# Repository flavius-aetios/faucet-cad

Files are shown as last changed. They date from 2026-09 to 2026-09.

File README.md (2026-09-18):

# Проставка для кухонного смесителя

Параметрическая модель CadQuery, которая меняет наклон выдвижной лейки,
чтобы направить струю вертикально. Текущий вариант рассчитан на коррекцию **13°**
по фотографии и посадочную часть лейки **Ø22 × 23 мм**.

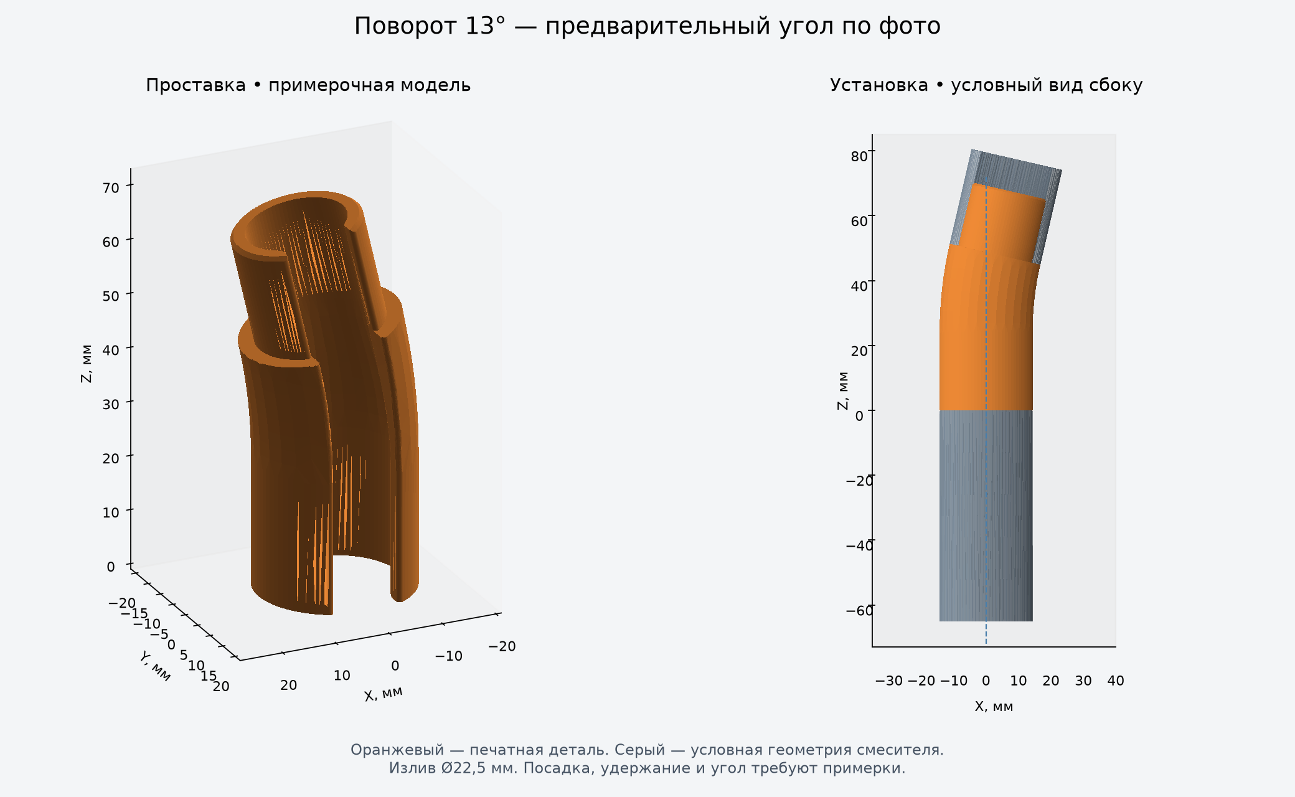
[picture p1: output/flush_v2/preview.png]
Вариант v2 и условная схема установки


**Состояние на 18.09.2026:** выбраны нижний **IN 22.6** и верхний **OUT 23.0**.
Подготовлен [вариант v2 для согласования и анализ печати](PROPOSAL_V2.md):
корпус Ø28,5 мм заподлицо на стыках, паз 12 мм, скругления R0,6 мм.
Новые STL/STEP находятся в **[output/flush_v2](output/flush_v2/)**;
старые файлы в корне `output/` сохранены для сравнения.
Результаты примерок записаны в [FIT_LOG.md](FIT_LOG.md).
Внутренний диаметр излива измерен: **22,5 мм**. Цель — плотная верхняя посадка
адаптера и свободное скольжение лейки в нижней. Надёжность удержания и фактическое
направление струи предстоит проверить. STL уточнён после замечания о видимых гранях.

## Что сохранено

- [model.py](model.py) — исходник модели; [parameters_flush_v2.json](parameters_flush_v2.json) —
  предлагаемые размеры; [parameters.json](parameters.json) — предыдущий вариант.
- [Фото референсы](<Фото референсы/>) — все четыре исходные фотографии с замерами.
- [output/flush_v2](output/flush_v2/) — новая полная проставка и два контрольных образца,
  условная сборка, изображения и отчёты; [output](output/) — также предыдущая серия.
- [PROPOSAL_V2.md](PROPOSAL_V2.md) — изменения, анализ сопла 0,4 мм и выбор PLA/PETG;
  [DESIGN.md](DESIGN.md) — исходная конструкция и история настройки окружения.
- `.vscode/` — настройки Python/OCP CAD Viewer и запуск через Ctrl+Shift+B.
- `pyproject.toml`, `uv.lock`, `.python-version` — воспроизводимое Python-окружение.

Папки `.venv`, кэши и временные диагностические установки в Git не включены:
окружение создаётся заново на другом компьютере из `uv.lock`.
STL уже можно открыть в Bambu Studio без установки CadQuery.

## Открыть на другом компьютере: Windows / PowerShell

Нужны Git, [uv](https://docs.astral.sh/uv/getting-started/installation/) и VS Code.
Для доступа к приватному репозиторию войти в свой аккаунт GitHub.

```powershell
git clone https://github.com/flavius-aetios/faucet-cad.git
Set-Location faucet-cad
uv sync --locked --cache-dir .uv-cache
code --install-extension ms-python.python
code --install-extension ms-toolsai.jupyter
code --install-extension bernhard-42.ocp-cad-viewer
code .
```

`uv` создаёт `.venv` с Python 3.11 и версиями библиотек из lock-файла.
Путь клонирования может быть любым: настройки проекта используют `${workspaceFolder}`.
Открывать в VS Code нужно **папку проекта**, чтобы её настройки применились.

1. Если VS Code не выбрал Python автоматически, выполнить `Python: Select Interpreter`
   и выбрать `.venv\Scripts\python.exe` внутри клонированной папки.
2. Открыть `model.py`: справа должен открыться OCP CAD Viewer.
3. Для нового варианта: **Terminal → Run Task → OCP: Show flush rounded v2 proposal**.
   **Ctrl+Shift+B** показывает прежнюю модель для сравнения. Открытие исходника само
   по себе не отправляет модель; задача выполняет программу с `--view`.

Альтернатива из терминала в папке проекта:

```powershell
& '.\.venv\Scripts\python.exe' '.\model.py' --parameters parameters_flush_v2.json --output-dir output/flush_v2 --view
```

Для генерации файлов без Viewer и проверки результата:

```powershell
& '.\.venv\Scripts\python.exe' '.\check_environment.py'
& '.\.venv\Scripts\python.exe' '.\model.py' --parameters parameters_flush_v2.json --output-dir output/flush_v2
& '.\.venv\Scripts\python.exe' '.\verify_exports.py' --output-dir output/flush_v2
& '.\.venv\Scripts\python.exe' '.\analyze_print.py' --output-dir output/flush_v2
```

Сохранённые отчёты относятся к исходному компьютеру; эти команды обновляют их
по результатам проверок на новом компьютере.

## Уже исправленные проблемы окружения

- **Python падает при завершении:** на Windows совместная загрузка CasADi 3.8.0
  и NLopt 2.11.0 приводила к `0xC0000005`. Зафиксирована проверенная пара
  **CasADi 3.8.0 / NLopt 2.9.1**. Использовать `uv sync --locked`, чтобы сохранить её.
- **PowerShell: неожиданный токен `-m`:** расширению задан префикс `& ` через
  `OcpCadViewer.advanced.shellCommandPrefix`. После изменения настроек выполнить
  `Developer: Reload Window`. В ручных командах перед путём к Python в кавычках
  также нужен `&`.
- **В Viewer логотип OCP:** выполнить `model.py --view` или Ctrl+Shift+B.

Инструкции и настройки VS Code проверены на Windows с PowerShell. При переносе
на Linux/macOS путь к Python — `.venv/bin/python`; нужно также изменить Windows-путь
в `.vscode/tasks.json`/`settings.json` и убрать PowerShell-префикс `& `.

## Следующий шаг: контрольные образцы v2

Для рабочей детали предлагается PETG, PLA подходит для примерок. Изменение
материала, паза и толщины стенок требует проверки посадок на новой геометрии.
Сначала напечатать в выбранном материале:

- [OUT 23.0 v2](output/flush_v2/pin_gauge_OD_23.0.stl) — верхняя посадка длиной 20 мм.
- [IN 22.6 v2](output/flush_v2/socket_gauge_ID_22.6.stl) — короткий нижний образец.

На всех образцах есть выпуклые подписи: **IN** — внутренний диаметр,
**OUT** — наружный, затем размер в миллиметрах. Образцы можно печатать вместе
на одной пластине и различать по надписям. [Пример маркировки](output/flush_v2/labeled_samples.png).
Штрихи утолщены до **1 мм**, точка увеличена до **1,2 мм**, рельеф — **0,8 мм**.
Новая серия лежит отдельно от старой; надписи обозначают размер, а не ревизию.

Для сопла 0,4 мм: слой 0,2 мм, 4 стенки, масштаб 100%. Проверить каждый образец
рукой без запрессовки: не входит / входит плотно / есть люфт. По результату изменить
зазоры в `parameters_flush_v2.json`, затем пересоздать вариант v2.

Адаптер должен оставаться в изливе при извлечении лейки. Отдельной защёлки пока нет:
верхняя посадка удерживается трением, возвратный шланг возвращает лейку в адаптер.
Анализ стенок и нависаний, настройки и порядок установки описаны
в [PROPOSAL_V2.md](PROPOSAL_V2.md).

## Сохранить дальнейшие изменения

После изменения размеров и повторной генерации:

```powershell
git add .
git commit -m "Update adapter dimensions and printable models"
git push
```

На другом компьютере перед началом работы: `git pull`, затем
`uv sync --locked --cache-dir .uv-cache`.

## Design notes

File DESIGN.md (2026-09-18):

# Угловая проставка для выдвижной лейки

**Обновление 18.09.2026:** пользователь выбрал верхний образец **OUT 23.0**.
Подготовлен [вариант v2 для согласования](PROPOSAL_V2.md): корпус Ø28,5 мм,
паз 12 мм, скругления R0,6 мм; файлы в `output/flush_v2/`.
Параметры и инструкции ниже описывают **предыдущую версию**, сохранённую для сравнения.

Текущая версия — модель для проверки посадки. Проставка меняет положение всей
лейки и устанавливается между лейкой и изливом. Вода остаётся в штатном шланге.
Паз сбоку позволяет надеть проставку на шланг, не разбирая соединение.

**Примерка 17.09.2026:** нижний образец IN 22.6 подошёл. Верхние образцы до
OUT 22.6 включительно не обеспечили нужного удержания. Подготовлена следующая
серия OUT 22.7 / 22.8 / 22.9 / 23.0. Подробности: [FIT_LOG.md](FIT_LOG.md).
Полную проставку пока не печатать: её верхний хвостовик ещё не подобран.

## Исходные размеры

| Параметр | Значение | Основание |
|---|---:|---|
| Посадочная часть лейки | Ø22 × **23 мм** | Фото и поправка пользователя; оранжевые 12 мм ошибочны |
| Корпус лейки | Ø28,5 мм | Фото с размерами |
| Жёсткий буртик соединителя | Ø12 мм | Уточнение пользователя |
| Шланг | Ø11 мм | Уточнение пользователя |
| Глубина отверстия излива | Немного больше 23 мм | Уточнение пользователя; дальше изгиб |
| Внутренний диаметр излива | **22,5 мм** | Измерен пользователем 10.09.2026 |
| Коррекция угла | **13°** | Оценка по общему фото; пользователь поручил оценить по фото |

На общем фото направление корпуса лейки отличается от вертикальной стойки
примерно на 12–15°. Камера даёт перспективное искажение; точность 13° не является
результатом измерения. При примерке нужно проверить фактическое направление струи.

## Геометрия текущей версии

- Нижняя посадка Ø22,6 мм, глубина прямого участка 24 мм: диаметральный зазор
  0,6 мм и запас по высоте 1 мм. Диаметр выбран по успешной примерке короткого образца;
  скольжение по всей длине 23 мм ещё предстоит проверить на полной детали.
- Верхний хвостовик Ø22,5 мм, длина 20 мм, фаска на входе 0,6 мм.
  Это оставленный в полной модели прежний размер, который НЕ обеспечивает
  нужное удержание. Заменить его после выбора нового образца; это не размер к печати.
- Внутренний проход в хвостовике Ø18 мм; боковой паз 13 мм.
- Корпус Ø30,5 мм; поворот между нижней и верхней осями 13°.
- Высота между опорной плоскостью корпуса лейки и торцом излива 48 мм.
  В первой версии этот запас оставлен для соединителя и изгиба шланга.
  Лейка окажется ниже штатного положения; после примерки длину можно уменьшить.
- Общий габарит детали приблизительно 33,3 × 29,1 × 69,9 мм.

Целевая посадка: **адаптер плотно удерживается в изливе, лейка скользит в адаптере**.
Лейка должна выниматься без вытягивания адаптера, но не иметь заметного бокового
люфта. Для верхней посадки подбирается фактический натяг по печатным образцам;
совпадение чисел Ø22,5 в CAD само по себе удержание не гарантирует.
В модели **нет отдельной защёлки, магнита или механического стопора от проворота**.
Натяжение штатного шланга возвращает лейку в нижнее гнездо. Если трения верхнего
хвостовика недостаточно и адаптер вращается или выходит вместе с лейкой,
потребуется доработка крепления. Образцы проверяют посадку, но не заменяют
проверку удержания всей конструкции при многократном извлечении лейки.

Длина жёсткого соединителя над посадочной частью не измерена. Поэтому отсутствие
его контакта со стенкой и свободный изгиб шланга проверяются при сборке.
Не вдавливать деталь, если шланг или соединитель упирается.

## Файлы

- `model.py` — параметрическая модель CadQuery.
- `parameters.json` — все изменяемые размеры в миллиметрах.
- `output/adapter_prototype.stl` — полная деталь для **примерочной** печати.
- `output/adapter_prototype.step` — точная CAD-геометрия.
- `output/socket_gauge_ID_22.6.stl` — проверенный нижний образец с новой маркировкой;
  повторная печать для подбора диаметра не нужна.
- `output/pin_gauge_OD_22.7.stl`, `22.8`, `22.9`, `23.0` — новые образцы верхнего хвостовика
  с полной длиной посадки 20 мм, пазом 13 мм, входной фаской 0,6 мм и основанием
  толщиной 2 мм, чтобы образец не ушёл внутрь излива. Общая высота образца 22 мм.
- `output/assembly_reference.step` — иллюстрация установки, **не для печати**.
  Длины серых моделей лейки и излива условные; шланг, кнопка и механизм фиксации
  не воспроизведены.
- `output/preview.png` — обзор детали и установки.
- `output/labeled_samples.png` — пример маркировки образцов.
- `output/geometry_report.json`, `export_validation.json` — проверки геометрии и экспорта.
- `check_surface.py`, `output/surface_quality.json` — измерение гладкости изгиба
  и отклонения треугольников STL от исходной поверхности.

## Грани, замеченные в STL

Исходная поверхность изгиба — гладкая B-spline. На 4141 проверенной точке
её отклонение от идеального кругового изгиба менее 0,00000003 мм. Выраженные
треугольные пятна в просмотрщике связаны с плоскими гранями STL и их освещением.
В STL эти грани действительно присутствуют; в исходном CAD таких заломов нет.

Экспорт уточнён: линейный допуск 0,005 мм вместо 0,03 мм, угловой 0,03 рад
вместо 0,08 рад. Перед экспортом удаляется ранее рассчитанная сетка отрисовки.
В версии от 10.09 число треугольников полной детали выросло с 18 636 до 119 100. В выборочной
проверке середины рёбер и центров треугольников внешнего изгиба наибольшее
измеренное отклонение снизилось с 0,1055 до 0,0094 мм. Это выборочное измерение,
а не доказанная граница ошибки в каждой точке всей модели. STL остаётся
треугольной сеткой; освещение без сглаживания может показывать грани и после уточнения.
Параметры экспорта описаны в [документации CadQuery](https://cadquery.readthedocs.io/en/stable/importexport.html).

## Первая печать на Bambu Lab, PLA

На каждом образце есть единая с ним площадка 16 × 14 × 2 мм с выпуклой надписью
высотой **0,8 мм**. **IN 22.6** означает внутренний диаметр 22,6 мм (образец на лейку),
**OUT 22.7** — наружный диаметр 22,7 мм (образец в излив). Все пять образцов
подписаны своим фактическим размером из параметров модели. Площадка находится
снаружи кольца, напротив бокового паза, и не меняет посадочные поверхности.
Это дополнительно проверяется в генераторе сравнением геометрии до/после маркировки.

Можно загрузить нужные STL одновременно в Bambu Studio и разложить их на одной
пластине. Каждый STL — одно связное тело с собственной надписью; печатать
площадкой на столе, надписью вверх. При слое 0,2 мм надпись занимает четыре слоя
над площадкой. Смена цвета не обязательна. Старый шрифт заменён геометрическими
буквами и цифрами с постоянной шириной штриха **1,0 мм**; десятичная точка —
квадрат **1,2 × 1,2 мм**. У штрихов нет сужающихся тонких концов. Шрифт из системы
больше не используется. В предпросмотре слайсера проверить слои надписей:
геометрия и связность проверены, но нарезка конкретным профилем принтера здесь не выполнялась.

Нижний диаметр Ø22,6 уже выбран пользователем по примерке.
Для верхней посадки напечатать `pin_gauge_OD_22.7.stl`, `22.8`, `22.9`, `23.0`
и примерять от меньшего диаметра к большему. Выбрать образец, который входит
на всю длину рукой и устойчиво держится; не забивать и не вдавливать силой.
Относительно измеренных Ø22,5 новые образцы дают номинальный натяг по диаметру
0,2 / 0,3 / 0,4 / 0,5 мм. Это размеры CAD, фактические размеры печати могут отличаться.
После выбора подставить результат в параметры: например, Ø22,8 означает
`outlet_diametral_clearance = -0.3`. Список новой серии задан в `pin_test_diameters`.
Сохранять прежние настройки материала и печати, чтобы сравнение было осмысленным.
STL импортировать в миллиметрах, масштаб 100%; не масштабировать модель для подбора посадки.

Для предполагаемого сопла 0,4 мм стартовые настройки: штатный профиль вашего PLA,
слой 0,2 мм, 4 периметра, 5 верхних/нижних слоёв, заполнение 25–30%.
Образцы стоят плоским основанием на столе. Полная деталь экспортирована нижним
торцом на Z=0, хвостовиком вверх. В предпросмотре слайсера проверить нависания;
внутренний переход пологий, отдельные поддержки конструкцией не предусмотрены.
При недостаточной адгезии добавить кайму 4–5 мм. Профиль температуры выбирать
по конкретному PLA и пластине, модель принтера пока не уточнена.

PLA здесь используется для примерки. Для постоянной эксплуатации у горячего
крана материал стоит выбирать с учётом нагрева и нагрузки; PETG обычно применяют
для держателей и зажимов благодаря вязкости и температурной стойкости
([руководство Prusa](https://help.prusa3d.com/article/petg_2059)).

После примерки надеть проставку боком на шланг, вставить лейку в нижнюю часть,
а хвостовик — в излив. Повернуть проставку так, чтобы она компенсировала наклон
в плоскости изгиба крана. Поддерживая сборку рукой, проверить посадку, возврат
шланга и вертикальность небольшой струи. Пока удержание не проверено,
не считать конструкцию законченной.

## Запуск

```powershell
.\.venv\Scripts\python.exe model.py
.\.venv\Scripts\python.exe verify_exports.py
```

Для показа в уже открытом OCP CAD Viewer:

```powershell
.\.venv\Scripts\python.exe model.py --view
```

Открытие `model.py` показывает исходный код, а модель отправляется только при
выполнении программы с `--view`. В VS Code открыть именно папку `Смеситель`
(File → Open Folder), открыть Viewer и нажать **Ctrl+Shift+B**: задача
`OCP: Show faucet adapter` запускает нужный Python с нужными аргументами.

При запуске из любой папки PowerShell можно выполнить:

```powershell
Set-Location -LiteralPath 'C:\Users\mihai\Desktop\DIY\Смеситель'
& '.\.venv\Scripts\python.exe' '.\model.py' --view
```

Для автоматических команд расширения в `.vscode/settings.json` задан
`OcpCadViewer.advanced.shellCommandPrefix: "& "`. Это настройка для PowerShell:
путь к программе в кавычках требует оператора вызова `&`. Если открытый терминал
backend уже показал ошибку `Непредвиденный токен "-m"`, в нём можно повторить:

```powershell
& 'C:\Users\mihai\Desktop\DIY\Смеситель\.venv\Scripts\python.exe' -m ocp_vscode --backend --port 3939
```

Backend обслуживает измерения в Viewer; загрузку нашей геометрии выполняет
именно `model.py --view`. Для ручного запуска модели использовать другой терминал,
пока backend работает. После изменения настроек можно выполнить команду VS Code
`Developer: Reload Window`, чтобы расширение перезапустилось с новым префиксом.

Угол меняется в `correction_angle_deg`; посадки — в `socket_diametral_clearance`
и `outlet_diametral_clearance`. Измеренный диаметр излива задаётся параметром
`outlet_bore_diameter` (22,5 мм). Положительный зазор уменьшает хвостовик,
отрицательный задаёт номинальный натяг. Повторный запуск перезаписывает экспорт.

## Исправление ошибки Python при завершении

В исходном окружении CadQuery 2.8.0 / CasADi 3.8.0 / NLopt 2.11.0 импорт
проходил успешно, но процесс завершался с `0xC0000005` (access violation).
Минимальное воспроизведение: `import casadi; import nlopt`. По отдельности
CasADi, NLopt, OCP и VTK завершались с кодом 0.

Для Windows зафиксирована проверенная пара **CasADi 3.8.0 / NLopt 2.9.1**
в `pyproject.toml` и `uv.lock`. CadQuery и OCP не заменялись.
Обычный запуск модели не подавляет ошибки Windows и не использует принудительный
выход для обхода очистки памяти. `check_environment.py` запускает отдельные
проверки решателей и CadQuery, проверяет реальный код завершения и сохраняет отчёт.
Подобная проблема описана [в CadQuery #1911](https://github.com/CadQuery/cadquery/issues/1911)
и [в repackage-ocp](https://github.com/bernhard-42/repackage-ocp).

```powershell
uv sync --cache-dir .uv-cache
.\.venv\Scripts\python.exe check_environment.py
```

Если VS Code или Jupyter уже загрузил прежний NLopt, перезапустить его Python-ядро,
чтобы оно использовало обновлённую библиотеку.

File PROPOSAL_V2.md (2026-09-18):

# Вариант v2 для согласования — 18.09.2026

Пользователь выбрал верхний образец **OUT 23.0**. Нижняя посадка **IN 22.6**
подтверждена ранее. Подготовлен отдельный вариант с уменьшенным корпусом и
скруглённым пазом: [STL](output/flush_v2/adapter_prototype.stl),
[STEP](output/flush_v2/adapter_prototype.step),
[параметры](parameters_flush_v2.json).
Прежние файлы в корне `output/` сохранены для сравнения и относятся к прошлой серии.

Вариант v2 и условная установка

## Предлагаемые изменения

| Параметр | Предыдущая версия | Вариант v2 |
|---|---:|---:|
| Наружный диаметр корпуса | 30,5 мм | **28,5 мм** |
| Верхняя посадка полной детали | 22,5 мм, устаревший размер | **23,0 мм**, выбран по образцу |
| Нижняя посадка | 22,6 мм | 22,6 мм |
| Ширина бокового паза | 13 мм | **12 мм** |
| Продольные углы паза | Острые | **R0,6 мм**, наружные и внутренние |
| Внутреннее сужение | Сосредоточено в конце изгиба | Плавно распределено по изгибу |

Корпус совпадает по номинальному диаметру с изливом и лейкой в местах стыков;
прежняя наружная ступенька 1 мм на сторону убрана. Это не герметичный стык:
реальная печать и подвижная лейка оставляют зазоры. Изгиб выступает в сторону
от нижней оси, поэтому общий габарит по X около 32,6 мм не означает диаметр 32,6 мм.
Поверхность в зоне изгиба аппроксимируется CAD-лофтом между круговыми сечениями.

Паз 12 мм оставляет номинально 1 мм относительно мягкого шланга Ø11 мм.
Скругления снимают углы, сохраняя ширину узкой части паза. Адаптер надевается
сбоку на мягкий участок шланга: жёсткий буртик Ø12 мм через паз с нулевым зазором
пропускать не предполагается. Торцы имеют прежние входные фаски 0,6 мм;
R0,6 относится именно к продольным краям паза, а не ко всем рёбрам детали.

Прямой участок нижнего гнезда по-прежнему 24 мм, хвостовик 20 мм,
расстояние между торцами лейки и излива 48 мм, угол 13° по фото.
Внутреннее сужение начинается выше прямого гнезда; его конечный проход Ø18 мм.
Длину жёсткого соединителя не измеряли, поэтому свободный изгиб шланга и отсутствие
упора соединителя проверяются на полной детали.

## Печать соплом 0,4 мм

Номинальная радиальная толщина вдали от скруглений паза:

| Участок | Толщина |
|---|---:|
| Нижнее гнездо | **2,95 мм** |
| Край нижней входной фаски | 2,35 мм |
| Верхний хвостовик | **2,50 мм** |
| Край верхней входной фаски | 1,90 мм |

Эти размеры допускают несколько линий экструзии соплом 0,4 мм. Они не являются
расчётом прочности или доказанной минимальной толщиной во всех точках скруглений.
Уменьшение корпуса ослабляет нижнее разрезное кольцо; более узкий паз и смена
материала тоже меняют его упругость. Старые результаты примерки не гарантируют
одинаковую силу удержания новой детали.

Ориентация: **широким нижним торцом на стол, хвостовиком вверх**, как экспортировано.
Так кольцо пружинит преимущественно в плоскости слоёв. Изгиб всей проставки
при рывке лейки всё равно нагружает связи между слоями.

Проверка нормалей STL после сглаживания внутреннего перехода дала максимум
**16,65° от вертикали** для нависающих поверхностей выше нижней фаски.
Площадь таких поверхностей круче 45° — **0 мм²**. Контакт со столом и зона
нижней входной фаски до Z=0,61 мм исключены из этой оценки. Нижняя фаска имеет
наклон 45°. По этой геометрии поддержки не требуются. Это анализ поверхности,
а не проверка траекторий, охлаждения и качества конкретного профиля слайсера.

Стартовые настройки для Bambu Studio:

- Сопло 0,4 мм, масштаб **100%**, слой **0,2 мм** для примерки или **0,16 мм**
  для более гладкой внешней поверхности.
- **4 периметра**, 5 верхних и нижних слоёв, заполнение 30%. В тонких стенках
  большую часть сечения займут периметры; заполнение 100% не обязательно.
- Поддержки выключены; перед печатью проверить послойный предпросмотр.
- При необходимости кайма 4–5 мм, особенно для высокой полной детали.
- Шов разместить со стороны паза, по возможности вне основных посадочных дуг.
  Сохранить проверенную компенсацию первого слоя и не масштабировать деталь
  для исправления посадки.
- Температуры, обдув и подготовка пластины — по профилю конкретного филамента
  и принтера. Модель Bambu Lab и марка филамента пока не указаны.

Маркировка образцов сохранена: штрих 1 мм, квадратная точка 1,2 мм,
выпуклый рельеф 0,8 мм. При слое 0,2 мм это четыре слоя над площадкой.

## PLA или PETG

**Предлагаю PETG для рабочей детали, PLA оставить для примерок.** Для разрезного
зажима полезны вязкость, хорошее сцепление слоёв и более высокая температурная
стойкость PETG. PLA проще печатать, но он более хрупкий и хуже переносит нагрев;
для постоянно нагруженной посадки рядом с горячим краном это нежелательно.
Свойства описаны в руководствах производителя:
[PETG](https://help.prusa3d.com/article/petg_2059),
[PLA](https://help.prusa3d.com/article/pla_2062).

Это выбор материала для следующего прототипа, а не гарантия долговременного
удержания. При нагреве и длительной нагрузке посадка может ослабевать.
PETG обычно хуже переносит нависания и чаще даёт нити, поэтому здесь полезны
пологий внутренний переход и сухой филамент по инструкции его производителя.
После смены PLA на PETG посадку нужно проверить заново.

## Что напечатать следующим

Перед полной деталью напечатать в выбранном материале два компактных образца:

- [OUT 23.0 v2](output/flush_v2/pin_gauge_OD_23.0.stl) — паз 12 мм, R0,6,
  полная длина посадки 20 мм и ограничительный фланец Ø28,5 мм.
- [IN 22.6 v2](output/flush_v2/socket_gauge_ID_22.6.stl) — новая толщина стенки,
  паз 12 мм и R0,6. Короткое кольцо экономит материал, но не проверяет скольжение
  лейки по всей глубине 24 мм.

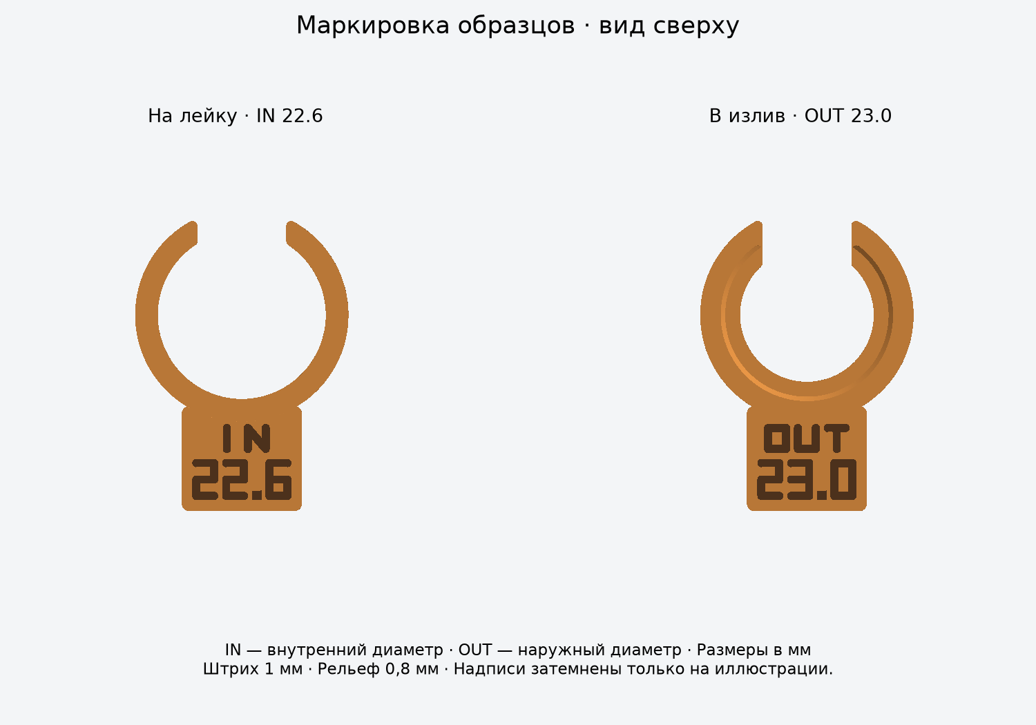
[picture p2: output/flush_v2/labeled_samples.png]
Образцы v2


Надписи обозначают размеры, а не ревизию. Не смешивать эти образцы со старыми:
у новых ширина паза 12 мм, видны скругления, наружный фланец 28,5 мм.
Выбранные Ø23,0 и Ø22,6 сохраняем до результатов проверки новой геометрии.
После печати полной детали проверить удержание при извлечении лейки,
отсутствие проворота, свободный шланг и направление струи.

## Воспроизведение и проверка

В VS Code: **Terminal → Run Task → OCP: Show flush rounded v2 proposal**.
Стандартная задача Ctrl+Shift+B пока показывает прежний вариант для сравнения.
Для новой версии из терминала в папке проекта:

```powershell
& .\.venv\Scripts\python.exe model.py --parameters parameters_flush_v2.json --output-dir output/flush_v2 --view
& .\.venv\Scripts\python.exe verify_exports.py --output-dir output/flush_v2
& .\.venv\Scripts\python.exe analyze_print.py --output-dir output/flush_v2
```

Все три STEP прошли проверку валидности единого тела; все три STL — проверку
замкнутости, связности, согласованности ориентации и объёма относительно STEP.
Отчёты: [геометрия](output/flush_v2/geometry_report.json),
[экспорт](output/flush_v2/export_validation.json),
[печать](output/flush_v2/print_analysis.json).
Пересечение хвостовика с условным изливом в отчёте ожидаемо: CAD Ø23,0 больше
измеренного отверстия Ø22,5. Это номинальный натяг; упругая деформация и реальные
печатные размеры в CAD-сборке не моделируются.

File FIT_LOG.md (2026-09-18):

# Результаты примерок

## 18.09.2026 — выбран OUT 23.0, предложена ревизия v2

Пользователь распечатал следующую серию: **23,0 мм подходит лучше всего**.
Нижняя посадка остаётся 22,6 мм. Эти номиналы перенесены в
`parameters_flush_v2.json`; прежний `parameters.json` сохранён для сравнения.

Пользователь измерил наружный диаметр тестового корпуса 30,5 мм и уточнил,
что наружные диаметры излива и лейки 28,5 мм. Предложен корпус 28,5 мм,
паз 12 мм для мягкого шланга 11 мм, скругления продольных углов R0,6 мм.
Подробности и анализ печати соплом 0,4 мм: [PROPOSAL_V2.md](PROPOSAL_V2.md).

Из-за изменения стенки, паза и возможного перехода на PETG подготовлены два
контрольных образца в `output/flush_v2/`. Сам вариант v2 ещё не примеряли.
Нижеследующие записи относятся к предыдущим этапам и не описывают статус v2.

## 17.09.2026 — первая печатная серия

Со слов пользователя, материал PLA, принтер Bambu Lab. Точные профиль и модель
принтера, измеренные размеры напечатанных деталей не сообщались.

| Образец | Результат | Решение |
|---|---|---|
| socket_gauge_ID_22.6 | Подошёл | Принять нижний диаметр 22,6 мм; на полной детали проверить всю длину посадки |
| pin_gauge_OD, вплоть до 22.6 | Держится слабо, выпадает от небольшого касания | Увеличить тестовые диаметры до 22,7 / 22,8 / 22,9 / 23,0 мм |
| Маркировка прежних образцов | Плохие надписи, пропуски и точки | Штрих 1,0 мм, квадратная точка 1,2 мм, рельеф 0,8 мм |

Размеры в названиях — номиналы CAD. Измеренный внутренний диаметр излива —
22,5 мм; его не меняем по косвенным результатам печати. Слабая посадка образца
22,6 мм сама по себе не доказывает ошибку этого измерения.

Новая серия сохраняет длину посадки 20 мм, проход Ø18 мм, паз 13 мм и фаску
0,6 мм. Изменён только наружный диаметр посадки и нерабочая маркировка.
Уже найденный нижний образец сохранён с новой надписью, остальные старые образцы
убраны из `output/`, чтобы не перепутать серии.

**Полная проставка ещё не готова к окончательной печати.** В ней нижний диаметр
изменён на 22,6 мм, верхний пока оставлен прежним (22,5 мм). После следующей
примерки заменить `outlet_diametral_clearance` на `22.5 - выбранный диаметр`.

Примерять новые образцы от меньшего к большему, не забивать. Нужен размер,
который входит на всю длину и не выпадает от касания. Затем на полной проставке
проверить, что извлечение лейки не вытягивает адаптер и не проворачивает его.

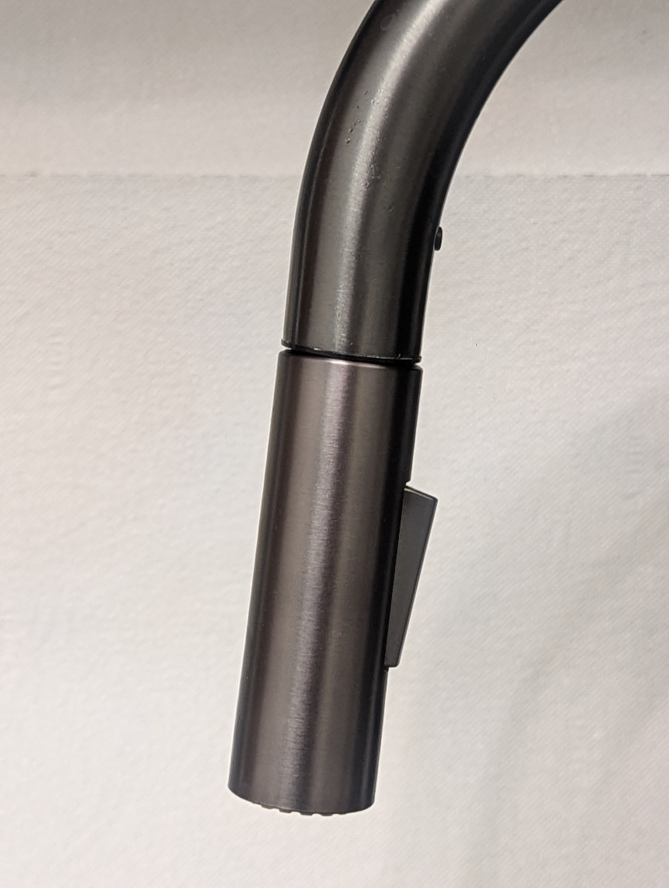
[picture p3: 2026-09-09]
Фото референсы/Крупный план форсунки.jpg

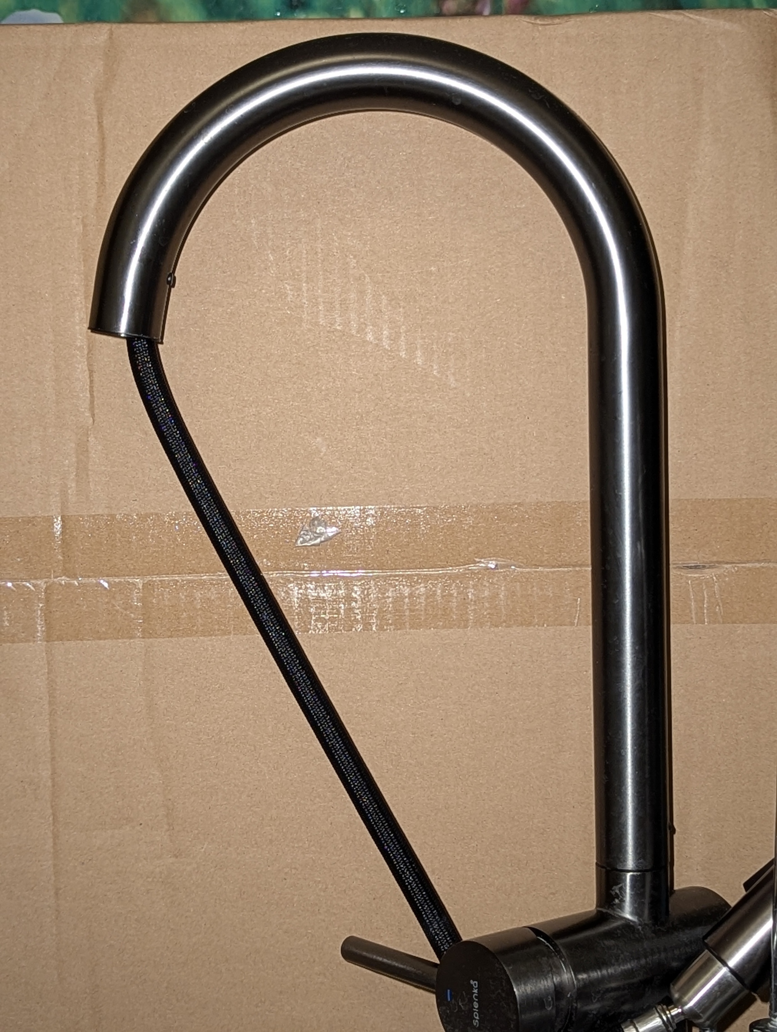
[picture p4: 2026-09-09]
Фото референсы/Общий вид с выдвинутой форсункой.jpg

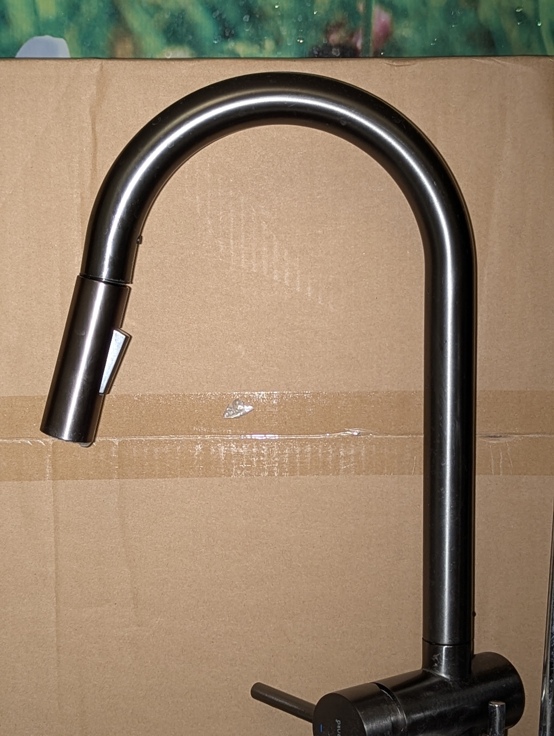
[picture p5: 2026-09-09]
Фото референсы/Общий вид на смеситель.jpg

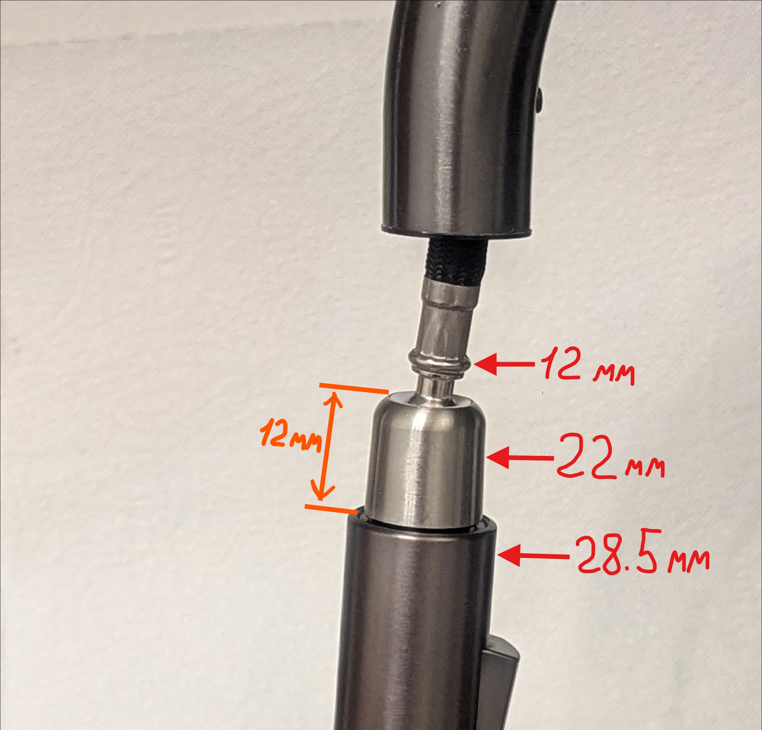
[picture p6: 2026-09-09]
Фото референсы/Размеры_.jpg

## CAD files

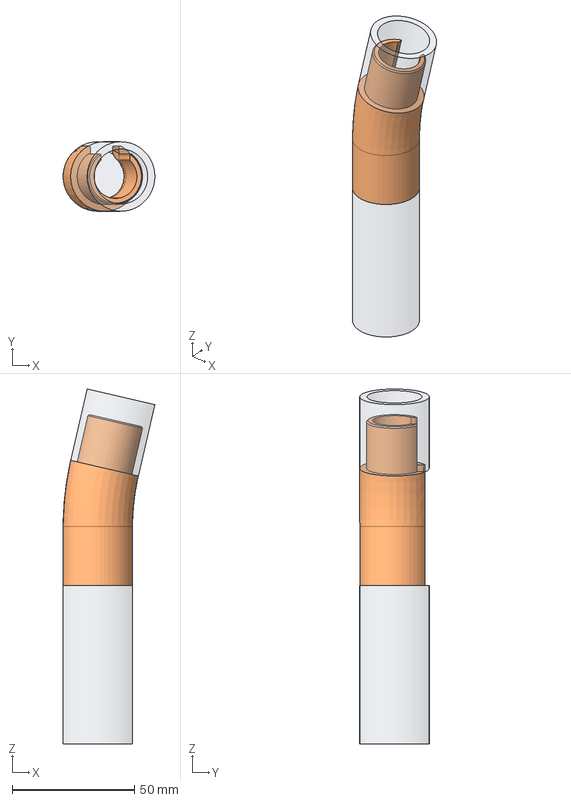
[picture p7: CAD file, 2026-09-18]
output/flush_v2/assembly_reference.step
37.6 x 28.5 x 145.4 mm
Adapter
Head_approximate
Outlet_approximate

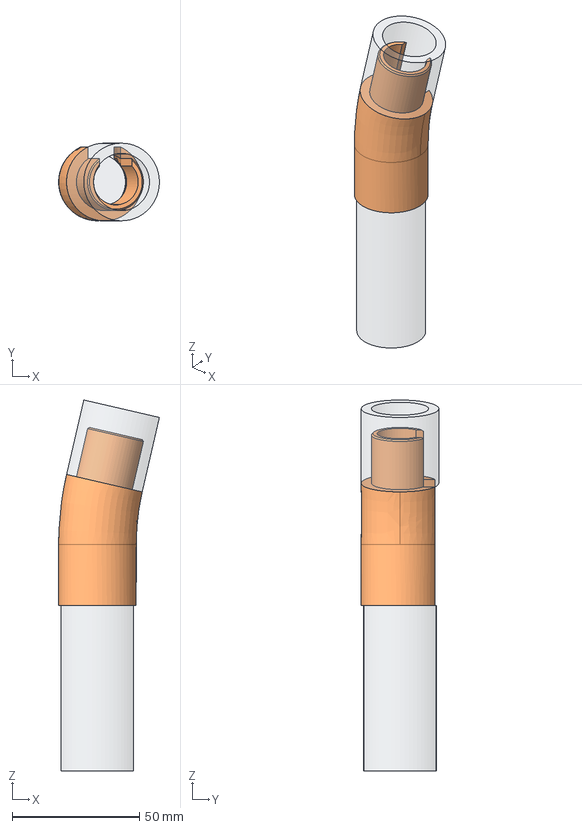
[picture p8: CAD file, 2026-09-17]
output/assembly_reference.step
39.6 x 30.5 x 145.7 mm
Adapter
Head_approximate
Outlet_approximate

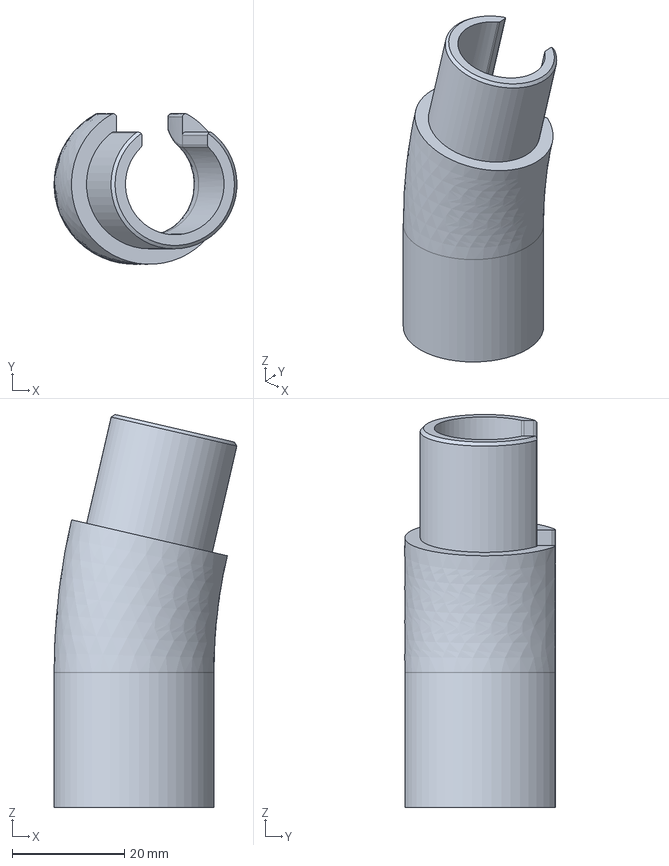
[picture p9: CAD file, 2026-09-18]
output/flush_v2/adapter_prototype.step
32.5 x 26.8 x 69.9 mm

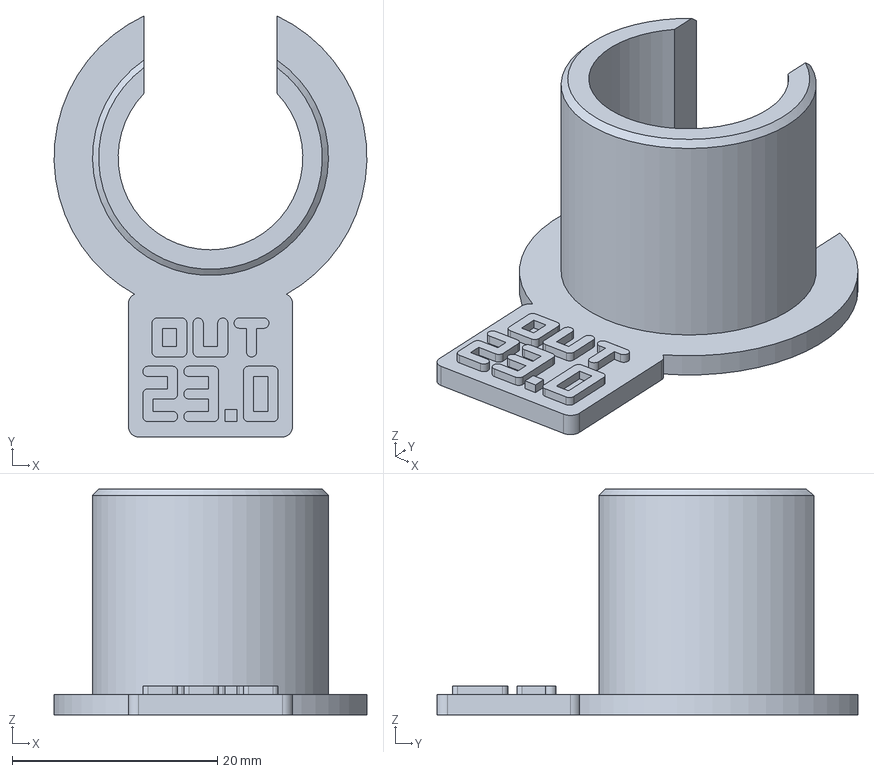
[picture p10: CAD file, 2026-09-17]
output/pin_gauge_OD_23.0.step
30.5 x 41.0 x 22.0 mm

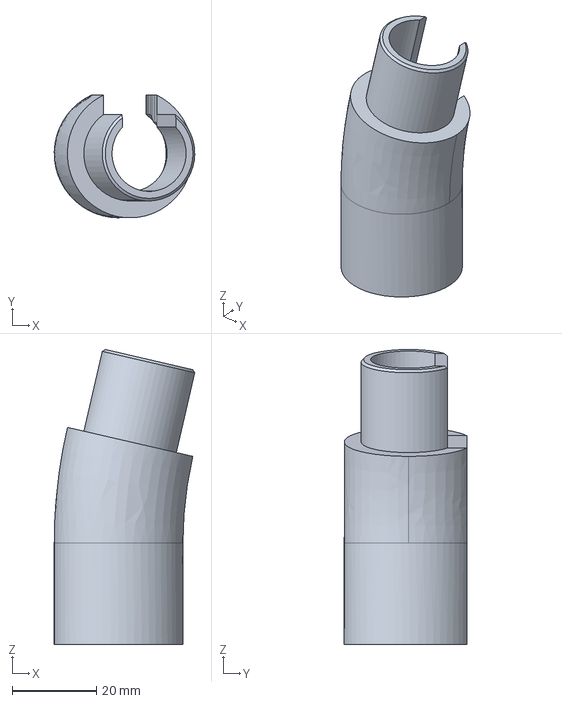
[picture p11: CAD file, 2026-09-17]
output/adapter_prototype.step
33.3 x 29.0 x 69.9 mm

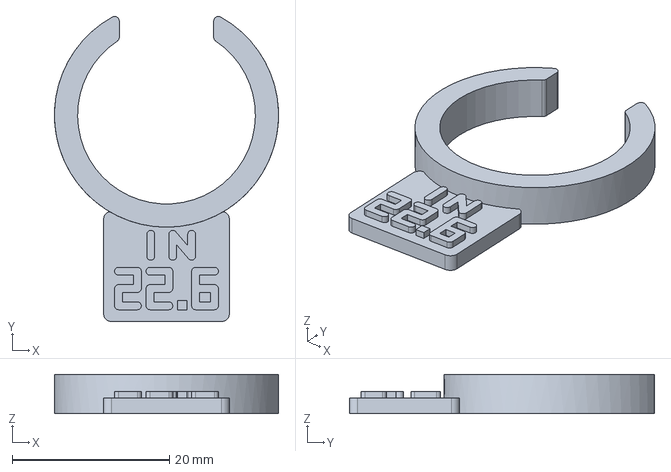
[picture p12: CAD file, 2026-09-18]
output/flush_v2/socket_gauge_ID_22.6.step
28.5 x 38.8 x 5.00 mm

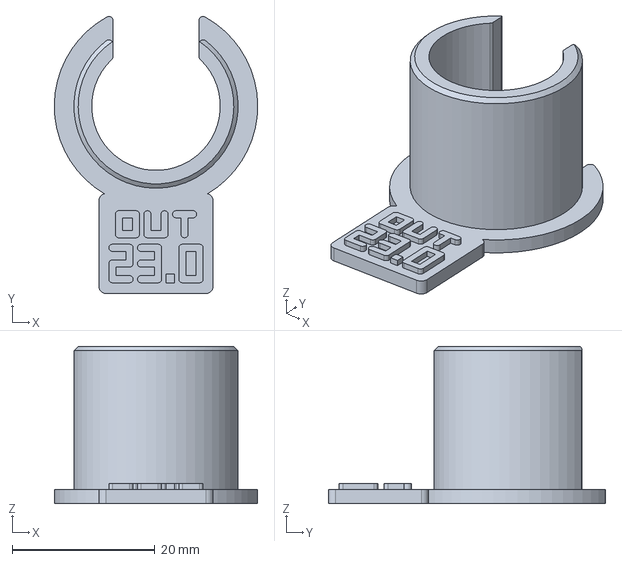
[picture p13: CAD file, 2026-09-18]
output/flush_v2/pin_gauge_OD_23.0.step
28.5 x 38.8 x 22.0 mm

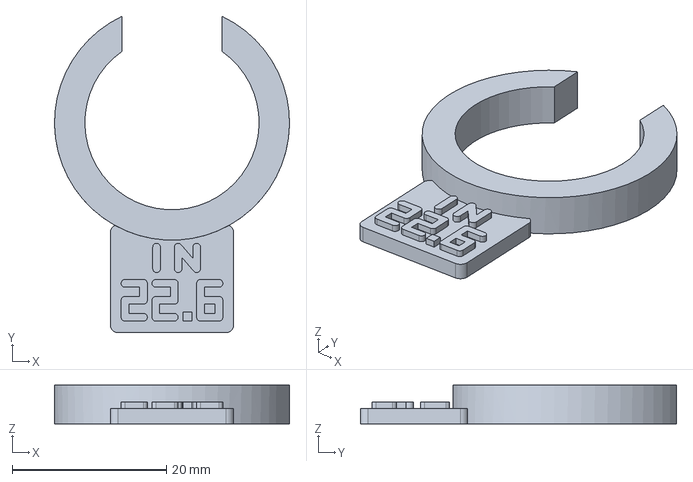
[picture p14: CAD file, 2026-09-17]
output/socket_gauge_ID_22.6.step
30.5 x 41.0 x 5.00 mm

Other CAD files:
output/pin_gauge_OD_22.9.step
output/pin_gauge_OD_22.7.step
output/pin_gauge_OD_22.8.step
output/adapter_prototype.stl
output/flush_v2/adapter_prototype.stl
output/flush_v2/pin_gauge_OD_23.0.stl
output/flush_v2/socket_gauge_ID_22.6.stl
output/pin_gauge_OD_22.7.stl
output/pin_gauge_OD_22.8.stl
output/pin_gauge_OD_22.9.stl
output/pin_gauge_OD_23.0.stl
output/socket_gauge_ID_22.6.stl

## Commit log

2026-09-09 Add faucet adapter CAD project, references and printable models
    [adapter_prototype.step, adapter_prototype.stl, assembly_reference.step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]
2026-09-10 Fit measured 22.5 mm outlet and refine STL surface mesh
    [adapter_prototype.step, adapter_prototype.stl, assembly_reference.step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]
2026-09-10 Add raised size labels to all fit samples
    [adapter_prototype.step, assembly_reference.step, pin_gauge_OD_22.3.step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]
2026-09-10 Trim label tabs on fit samples to save material
    [adapter_prototype.step, assembly_reference.step, pin_gauge_OD_22.3.step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]
2026-09-17 Add larger pin fit series and robust constant-width labels
    [adapter_prototype.step, adapter_prototype.stl, assembly_reference.step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]
2026-09-18 Add flush rounded adapter proposal and printability analysis
    [adapter_prototype.step, adapter_prototype.stl, assembly_reference.step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]
